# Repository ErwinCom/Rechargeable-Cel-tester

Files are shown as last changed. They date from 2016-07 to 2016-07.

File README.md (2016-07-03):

# Rechargeable-Cell-tester
Tester for rechargeable cells (li-ion, li-po, ni-mh, ni-cad)

This tester is derived of the work of: vwlowen

http://vwlowen.co.uk/arduino/battery-tester/batery-tester.htm

Adapted for personal use.

1. Changed PCB layout:
2. no power supply (power is supplied through usb connector)
3. No ftd232
4. changed arduino sketch

Files:

1. PCB, eagle format
2. Schematic, pdf and eagle format
3. casing design, laser cut 3mm plywood
4.

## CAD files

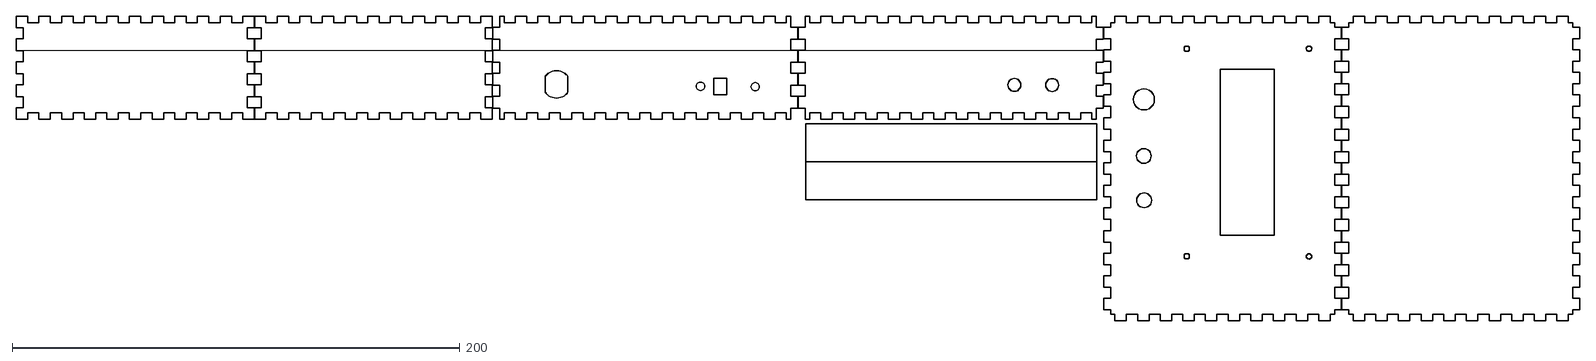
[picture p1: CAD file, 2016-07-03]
Box_bat_test_new.dxf
698.2 x 136.2

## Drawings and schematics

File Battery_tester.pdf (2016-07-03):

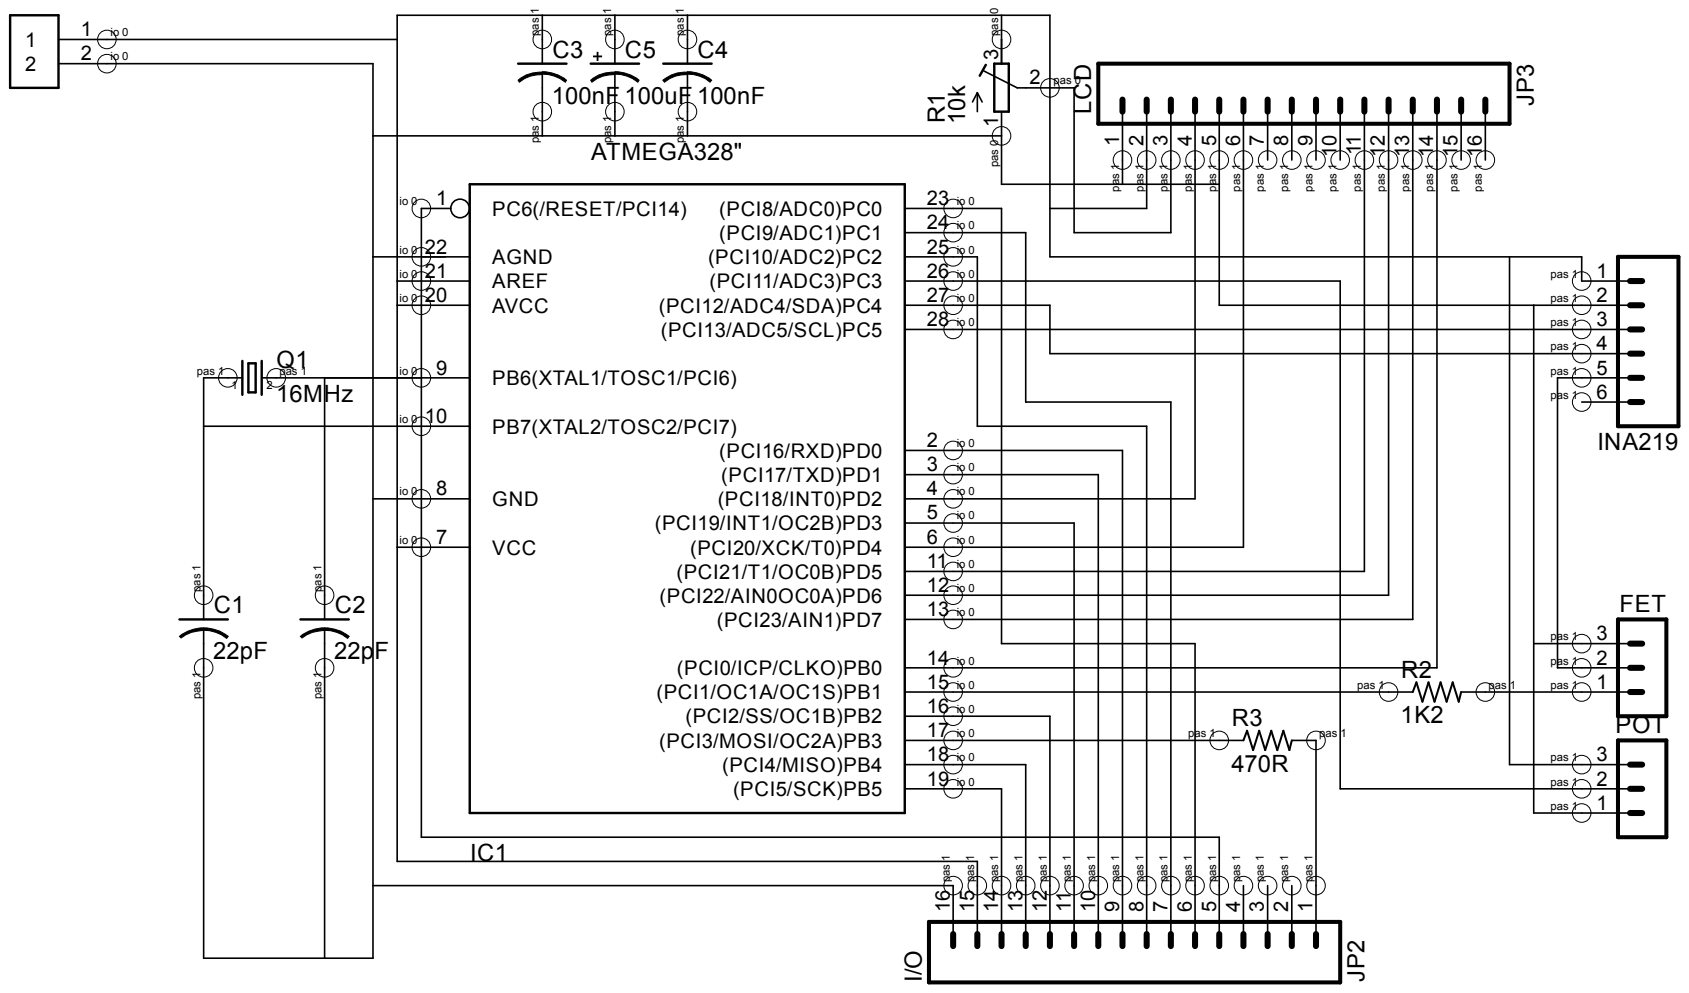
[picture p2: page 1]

io 0 | | AREF 21 | io 0
io 0 | | AVCC 20 | io 0

io 0 | | PB7(XTAL2/TOSC2/PCI7) 10

io 0 | 8
io 0 | 7 | 5 io 0

3 io 0
4 io 0

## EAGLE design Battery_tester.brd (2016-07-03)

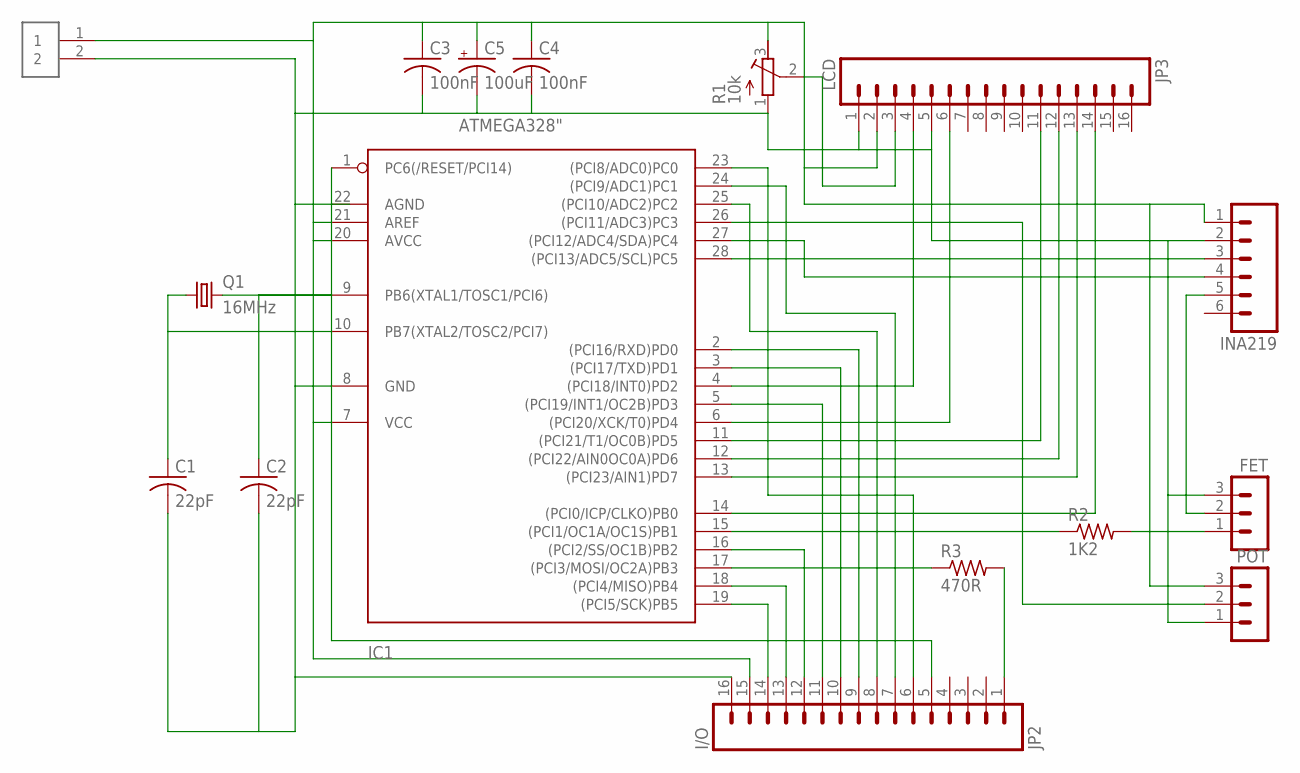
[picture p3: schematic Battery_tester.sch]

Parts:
C1, C2: 22pF; UNPOLARIZED_CAP
C3, C4: 100nF; UNPOLARIZED_CAP
C5: 100uF; ELECTROLYTIC_CAP
FET: MA03-1
I/O: JP2; 1X16_HEADER
IC1: ATMEGA328"; ATMEGA328
INA219: 1X06_HEADER"; 1X06_HEADER
JP3: LCD; 1X16_HEADER
POT: MA03-1
Q1: 16MHz; HC18U-V
R1: 10k; RTRIM3339P
R2: 1K2; RESISTOR
R3: 470R; RESISTOR
USB: 5V; 1X02_HEADER

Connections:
unnamed: JP3.3, R1.2 (S)
unnamed: C1.2, C2.2, C3.2, C4.2, C5.-, FET.3, I/O.16, IC1.8 (GND), INA219.2, JP3.1, JP3.5, POT.1, R1.1 (E), USB.2
unnamed: C1.1, IC1.10 (PB7(XTAL2/TOSC2/PCI7)), Q1.1
unnamed: C2.1, IC1.9 (PB6(XTAL1/TOSC1/PCI6)), Q1.2
unnamed: C3.1, C4.1, C5.+, I/O.15, IC1.7 (VCC), IC1.20 (AVCC), IC1.21 (AREF), INA219.1, JP3.2, POT.3, R1.3 (A), USB.1
unnamed: IC1.4 ((PCI18/INT0)PD2), JP3.4
unnamed: IC1.6 ((PCI20/XCK/T0)PD4), JP3.6
unnamed: IC1.11 ((PCI21/T1/OC0B)PD5), JP3.11
unnamed: IC1.12 ((PCI22/AIN0OC0A)PD6), JP3.12
unnamed: IC1.13 ((PCI23/AIN1)PD7), JP3.13
unnamed: IC1.14 ((PCI0/ICP/CLKO)PB0), JP3.14
unnamed: IC1.28 ((PCI13/ADC5/SCL)PC5), INA219.3
unnamed: IC1.27 ((PCI12/ADC4/SDA)PC4), INA219.4
unnamed: IC1.15 ((PCI1/OC1A/OC1S)PB1), R2.1
unnamed: FET.1, R2.2
unnamed: FET.2, INA219.5
unnamed: IC1.26 ((PCI11/ADC3)PC3), POT.2
unnamed: IC1.17 ((PCI3/MOSI/OC2A)PB3), R3.1
unnamed: I/O.1, R3.2
unnamed: I/O.14, IC1.19 ((PCI5/SCK)PB5)
unnamed: I/O.13, IC1.18 ((PCI4/MISO)PB4)
unnamed: I/O.12, IC1.16 ((PCI2/SS/OC1B)PB2)
unnamed: I/O.11, IC1.5 ((PCI19/INT1/OC2B)PD3)
unnamed: I/O.10, IC1.3 ((PCI17/TXD)PD1)
unnamed: I/O.9, IC1.2 ((PCI16/RXD)PD0)
unnamed: I/O.8, IC1.25 ((PCI10/ADC2)PC2)
unnamed: I/O.7, IC1.24 ((PCI9/ADC1)PC1)
unnamed: I/O.6, IC1.23 ((PCI8/ADC0)PC0)
unnamed: I/O.5, IC1.1 (PC6(/RESET/PCI14))

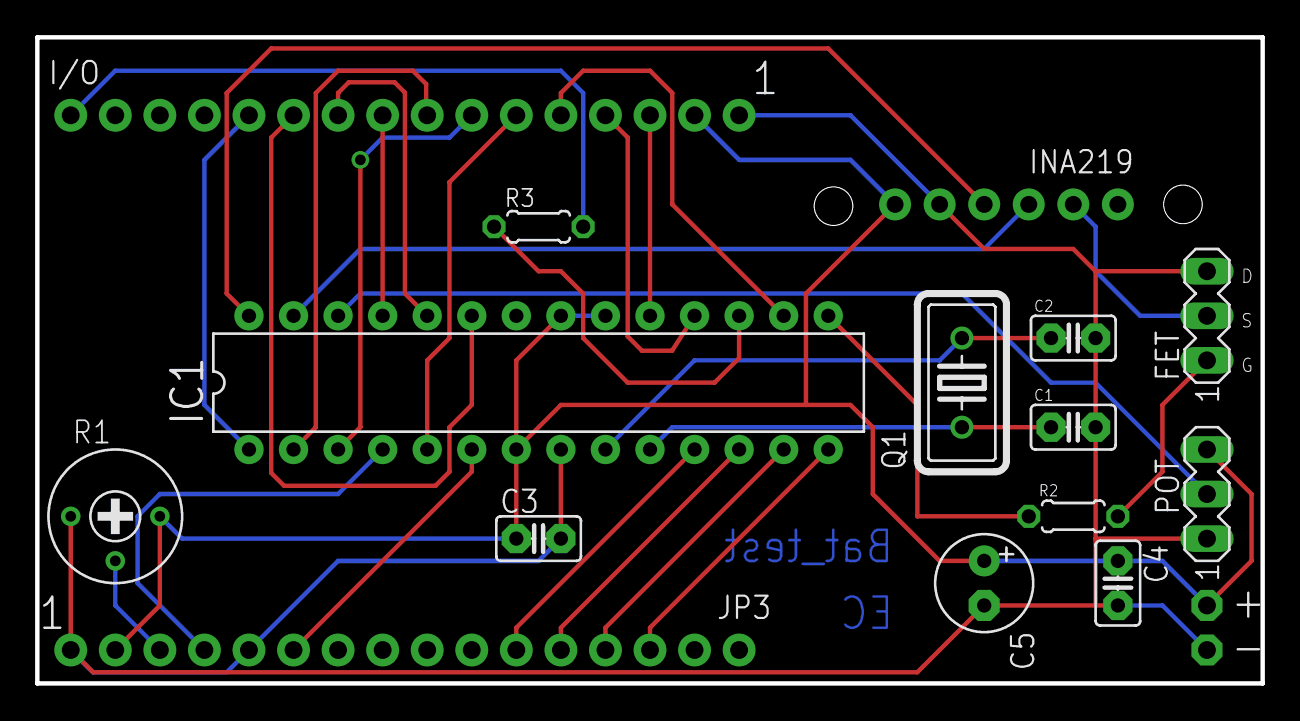
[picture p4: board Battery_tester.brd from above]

Board: 2 copper layers, 69.8 x 36.8 mm, 16 parts (0 on the bottom side), 29 nets.

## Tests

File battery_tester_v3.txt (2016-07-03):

 
/*  Lithium Battery Tester - works with hardware shown at vwlowen.co.uk/arduino/battery-tester/batery-tester.htm */

#include <TimerOne.h>                         //https://github.com/PaulStoffregen/TimerOne

#include <Wire.h>
#include <Adafruit_INA219.h>                  //https://github.com/adafruit/Adafruit_INA219    

#include <LiquidCrystal.h>

int end_sounder = A2;                        // Digital output for sounder
boolean sounded = false;

int end_pin = 11;                            // Output pin for end of test LED
int manual_pin = 12;                         // Manual/Run switch. Grounded in Manual.
int manual_value = A3;                       // Set target discharge current with potentiometer

int lcdRS = 2;                               // Define output pins for LCD
int lcdE = 4;
int lcdD4 = 5;
int lcdD5 = 6;
int lcdD6 = 7;
int lcdD7 = 8;

LiquidCrystal lcd(lcdRS, lcdE, lcdD4, lcdD5, lcdD6, lcdD7); 

byte bell[8] = {0, 4, 14, 14, 14, 31, 4, 0};  // Data for 'bell' character for LCD.

const byte pwm_pin = 9;                       // PWM DAC, only pins 9 and 10 are allowed
const byte period = 128;                      // for 10 bit DAC 

unsigned long  startMillisec;                 // Variables for discharge timer.
unsigned long  sampleTime = 10000;            // Default samples to PC time (ms)
unsigned long millis_PC_wait;                 // Timer for samples to PC
unsigned long millisCalc_mAh;                 // Timer for nexr mAh calc. and LCD write.

float hours;                                  // Working variables for time and mAh
float last_hours = 0.0;
int mins, secs, tMins;
float mAh_soFar = 0.0;

Adafruit_INA219 ina219;                       // Create instance for INA219 sensor library

int current_mA = 0;                       // Variables for INA219 readings
float busvoltage = 0.0;
float shuntvoltage = 0.0;
float loadvoltage = 0.0;
float battery_volts = 0.0;
float vR;                                     // Volt drop in circuit 

int target_mA = 0;                            // Default 'set point' variables
float cutoff_voltage = 3.0;
int time_limit = 180;
float offset = 0.0;
float error;

int cancel = 0;                               // Variables and flags to terminate test
boolean timed_out = false;
boolean high_current = false;
boolean cutoff_voltage_reached = false;

boolean manual = false;

int pwm = 0;                                     // Starting PWM value for 10-bit DAC
float kP = 30;                                   // Simple 'Proportional' control term
int tolerance = 1;                               // Deadband to stop 'hunting' around target value
int beep = 1;                                    // Sounder on/off  (0 = off, 1 = on)

/* === Set up - normal setup parameters and initialises values for the contol loop ===== */

void setup() {
  
  lcd.createChar(1, bell);                       // Bell char for LCD. Displayed when sounder is enabled.
   
  pinMode(manual_pin, INPUT);                    // MAN/RUN switch. Grounded in MAN position.
  digitalWrite(manual_pin, HIGH);                // Enable internal pullup resistor.
  
  pinMode(end_pin, OUTPUT);                      // Output to LD to signal end of test.
  digitalWrite(end_pin, LOW);
  
  pinMode(end_sounder, OUTPUT);                  // Output to sounder.
  digitalWrite(end_sounder, LOW);

  pinMode(pwm_pin, OUTPUT);                      // Set up 10-bit DAC pin as output
  Timer1.initialize(period);                     // 
  Timer1.pwm(pwm_pin, pwm);                      // and set zero PWM out
  
  ina219.begin();                                // Initialise INA219 Current Sensor

  Serial.begin(9600);                           // Initialise Arduino to PC Com Port
  
  lcd.begin(20, 4);                              // Initialize the LCD.
  lcd.clear();
  delay(100);
    lcd.setCursor(0, 0);
  lcd.print("Erwin Commandeur"); 
   lcd.setCursor(0, 1);
  lcd.print("Initialising...");                  // Print something on the display to show
  delay(1000);                                   // it's working.
  
  lcd.clear();                                   // Clear display
  delay(100);
  
  while (digitalRead(manual_pin) == HIGH) {          // Loop here to adjust desired load mA manually
     lcd.setCursor(0, 1); 
     lcd.print("Set mA: ");
     manual = true;
     target_mA = map(analogRead(manual_value), 0, 1023, 0, 1500);
     lcd.setCursor(10, 1);
     lcd.print("      ");
     lcd.setCursor(10, 1);
     lcd.print(target_mA); 
     time_limit = 480;                               // 8 hours. Test relies on the..
     cutoff_voltage = 3.0;                           // 3.0 volts cutoff voltage.
     kP = 30;                                        // Default values are used in Manual Mode.
     offset = 0;
     tolerance = 1;
     beep = 1;
     delay(100);
  }
  
//  if (!manual) {                                     // If not manual, must be under PC control.
//    lcd.setCursor(0, 1);
//    lcd.print("Waiting for settings");               // Prompt that we're waiting to receive
//    lcd.setCursor(6, 2);                             // the load settings from the application
//    lcd.print("from PC...");                         // that's running on the PC.
  
//    while (Serial.available() == 0 ) ;              // Wait for settings params from PC
//    if (Serial.available() > 0) {                   // Data available on serial port from PC
//      target_mA = Serial.parseInt();                // so read each one in turn into variables.
//      cutoff_voltage = Serial.parseFloat();         // Minimum battery voltage to end test
//      time_limit = Serial.parseInt();               // maximum time allowed for the test
//      sampleTime = Serial.parseInt() * 1000;        // Interval to send data to PC
//      kP = Serial.parseInt();                       // kP - control loop Proportional value
//      offset = Serial.parseFloat();                 // To reduce offset between target and actual mA
//      tolerance = Serial.parseInt();
//      beep = Serial.parseInt();                     // Sounder on/off   (0=off, 1=on)               
//    }
//    Serial.flush();                                 // Make sure the serial port is empty to avoid
                                                     // false 'Cancel' messages in the control loop.
//  }   

  /* These lines echo the received values to the LCD and display for 5 seconds  */
  
  lcd.clear();
  delay(100);
  lcd.print("Target mA   "); lcd.print(target_mA);
  lcd.setCursor(0, 1);
  lcd.print("Cutoff v    "); lcd.print(cutoff_voltage); 
  if (beep == 1) {
    lcd.setCursor(19, 0);
    lcd.write(1);
  }
  lcd.setCursor(0, 2); 
  lcd.print("Time (min)  "); lcd.print(time_limit); 
  lcd.setCursor(0, 3); lcd.print("S="); lcd.print(sampleTime/1000);
  lcd.print(" t="); lcd.print(tolerance); lcd.print(" kP="); lcd.print((int)kP);
  lcd.print(" i="); lcd.print(offset, 1); 

  delay(5000);
  lcd.clear();
  startMillisec = millis();                        // get millisec time at start
  if (beep == 1) {
    digitalWrite(end_sounder, HIGH);               // Bleep once to indicate test starting.
    delay(50);
    digitalWrite(end_sounder, LOW);  
  }
}

/* =========== Get Current and Voltage from Adafruin INA219 breakout board ============ */

void readINA219() {                                 // Function to read curent and voltage from INA219.
  float R = 0.12;                                   // "Tweaking" value to compensate for circuit resistance.
  int temp_mA = 0;
  float temp_V = 0;
  shuntvoltage = ina219.getShuntVoltage_mV();       // Get values for the INA219 sensor.
  
  for (int i = 0; i< 10; i++) {
    temp_V = temp_V + ina219.getBusVoltage_V();     // Take average of 10 readings for
    delay(10);                                      // Bus Voltage.......
  } 
  busvoltage = temp_V / 10; 
  
  for (int i = 0; i< 20; i++) {
    temp_mA = temp_mA + ina219.getCurrent_mA();     //...... and 20 reading for current.
    delay(10);
  }
  current_mA = temp_mA / 20;  
  vR = R * current_mA / 1000;                            // Total load voltage has to factor in the
  loadvoltage = busvoltage  + (shuntvoltage/1000) + vR;  // volt drop across the 0.1R shunt & circuit resistance.
  
}

/* ========== Main Loop ============================================================= */

void loop() {
  
  readINA219();                                              // Get current and voltage values.    

  /* Calculate error between target_mA and actual mA and apply to PWM value */
  
  error = abs(target_mA - current_mA);
  error = (error / target_mA) * 100;
  
  if ((error > tolerance)  ) {                              // If out of tolerance (deadband to stop 'hunting')
    error = error - offset;                                 // Bias (long term error compensation)
    error = (error * kP) / 100;                             // 'proportional' factor reduces impact of 'raw' error.
    error = constrain(error, 0.0, 25.0);
  
    if (current_mA > target_mA) error = -error;             // Determine if it's a pos or neg error.
  
    pwm =  abs(pwm + round(error));
    pwm = constrain(pwm, 0, 1023); 
  }

  if (current_mA > (target_mA * 2.0) ) {                     // Check if measured current has 
     pwm = 0;                                                // overshot the target value by more than
     Timer1.pwm(pwm_pin, pwm);                               // 100% and abort if it has.
     high_current = true;
     target_mA = 0;
     lcd.setCursor(3, 1);
     lcd.print("ERROR - Hi mA");
     Serial.print("MSGSTError - High mAMSGEND");
  }  

  if (loadvoltage < cutoff_voltage) {                        // Monitor battery voltage and finish
    delay(3000);                                             // the load test when it reaches the
    readINA219();                                            // target value.  Allow 3 seconds for
    if (loadvoltage < cutoff_voltage) {                     // short dip in battery voltage when
      pwm = 0;                                                 // load comes on.
      Timer1.pwm(pwm_pin, pwm);                                
      cutoff_voltage_reached = true;
      target_mA = 0;
      lcd.setCursor(5, 1);
      lcd.print("FINISHED");
      Serial.print("MSGSTTest FinishedMSGEND");
    }
  }
  
  if ((!cutoff_voltage_reached) && (tMins > time_limit)) {    // A time limit can also be set to
    pwm = 0;                                                 // abort the test if it appears to
    Timer1.pwm(pwm_pin, pwm);                                // be taking too long.
    timed_out = true;
    target_mA = 0;
    lcd.setCursor(2, 1);
    lcd.print("TIMED OUT");    
    Serial.print("MSGSTTime ExceededMSGEND");
  }
  
   if ((Serial.available() > 0)){                            // Monitor for input on the serial port
      cancel = Serial.parseInt();                            // A value of 999 sent from
      if (cancel == 999) {                                    // the PC means 'Cancel' the test.
        pwm = 0;
        Timer1.pwm(pwm_pin, pwm);
        target_mA = 0;
        lcd.setCursor(3, 1);
        lcd.print("CANCELLED");
        Serial.print("MSGSTUser cancelledMSGEND");
      } 
    }
  
  /* If all is ok, outout the PWM value to adjust the current.  */
     
  if   ((cancel == 0) && (!timed_out) && (!high_current) && (!cutoff_voltage_reached)) {
     Timer1.pwm(pwm_pin, pwm);                               // Adjust PWM to calculated value.
  }
  else {                                                     // otherwise sound the beep and light the
    digitalWrite(end_pin, HIGH);                             // End LED.
    if ((!sounded) && (beep == 1)) {
      sounded = true;
      for (int i = 0; i< 10; i++) {
        digitalWrite(end_sounder, HIGH);
        delay(50);
        digitalWrite(end_sounder, LOW);
        delay(50);
      }
    }
  }
  
  /* Calculate the elapsed time and the mA / hr used each second round the loop. Send to LCD and PC */
  
  getTime();

  if (millis() > millisCalc_mAh + 1000) {
    float this_hours = (millis() - startMillisec) / (1000.0 * 3600.0);    // Calculate mA used in this time sample
    mAh_soFar = mAh_soFar + ((this_hours - last_hours) * current_mA);     //
    last_hours = this_hours;  
    write_to_lcd();                                                       // Write data to LCD
    millisCalc_mAh = millis();
  }
  
  if (millis() > millis_PC_wait + sampleTime) {               // If the Sample-to-PC time has
      write_to_pc();                                          // elapsed, send data to the PC
      millis_PC_wait = millis();                              // and reset the elapsed time
  }                                                           // counter.
}

/* ==============  Write values to LCD ========================================== */

void write_to_lcd() {
  
    lcd.setCursor(0, 0);
    if (current_mA < 1000) lcd.print(" "); if (current_mA < 100) lcd.print(" ");
    if (current_mA < 10) lcd.print(" ");
    lcd.print(current_mA); lcd.print(" mA");
    lcd.setCursor(9, 0);                              //
    lcd.print(loadvoltage); lcd.print(" v  "); 
    
    if (beep == 1) {
      lcd.setCursor(19, 0);
      lcd.write(1);
    }    
    
    if ((cancel == 0) && (!timed_out) && (!high_current) && (!cutoff_voltage_reached)) {
      lcd.setCursor(0, 2);
      lcd.print("Time: "); 
      lcd.print((int)hours); lcd.print(":");
      if (mins < 10) lcd.print("0"); lcd.print(mins); lcd.print(":"); 
      if (secs < 10) lcd.print("0");
      lcd.print(secs);
      lcd.setCursor(0, 3);
      lcd.print("Used: "); lcd.print(mAh_soFar); lcd.print(" mAh");
    }
  
}

/* =================== Send values to PC =================================== */

void write_to_pc() {
  
  Serial.print("STARTC");  Serial.print(current_mA); Serial.println(" mAENDC");                                    

  /* Send time elapsed to PC. Formatting is done this end as it's easier than
     having to parse/unparse the string twice at the other end.  */
  Serial.print("STARTT"); Serial.print((int) hours); Serial.print(":");
  if (mins < 10) Serial.print("0"); Serial.print(mins); Serial.print(":");
  if (secs < 10) Serial.print("0"); Serial.print(secs); Serial.println("ENDT");
  
  /* Send mAh used so far, this sample's current and voltage to PC */
  Serial.print("STARTMAH"); Serial.print(mAh_soFar); Serial.println("ENDMAH");
  Serial.print("GRAPHCS"); Serial.print(current_mA); Serial.println("GRAPHCEND");
  Serial.print("GRAPHVS");  Serial.print(loadvoltage); Serial.println("GRAPHVEND");
  
  Serial.flush();        // Flush serial port before it returns to the main loop.
}

/* === Generic routine for hours, minutes and seconds between two millis() values.===*/
void getTime() {         
  char buffer[20];
  unsigned long nTime;
  unsigned long milli =  millis() - startMillisec;

  nTime = milli / 1000;
  tMins = nTime / 60;
  nTime = nTime % (24*3600);
  hours = nTime / 3600;
  nTime = nTime % 3600;
  mins  = nTime / 60;
  secs  = nTime % 60;
}

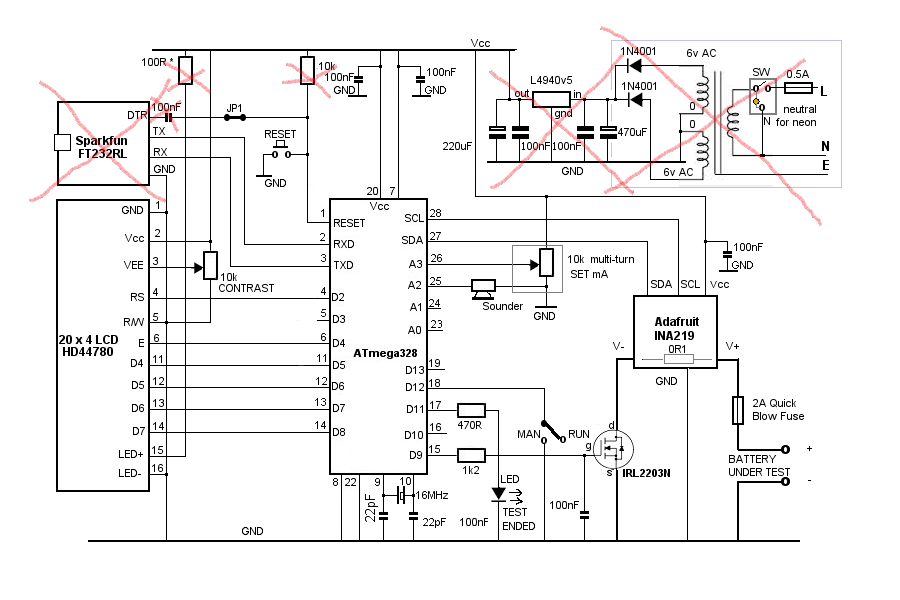
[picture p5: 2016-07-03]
battery-tester-circuit.png
